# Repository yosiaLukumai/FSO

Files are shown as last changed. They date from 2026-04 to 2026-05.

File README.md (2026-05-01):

# FSO - Free Space Optics Communication System

A fully working wireless optical link built from off-the-shelf components for under $330. Custom circuits, fabricated hardware, desktop software, and an AI-driven adaptive power controller - designed, built, and field-tested by two Mechatronics students in Tanzania.

---

## The Problem

Laying fiber or cellular infrastructure in rural Tanzania is expensive and often logistically impossible. Yet connectivity demand is growing - for communities, drone applications, and satellite ground links. Commercial FSO systems exist but are priced far out of reach for most local use cases.

We wanted to answer one question: how far can careful engineering with minimal budget take you?

---

## What We Built

A complete FSO link - transmitter, receiver, alignment system, desktop software, and an adaptive power controller - all designed and fabricated from scratch.

| Layer | What |
|---|---|
| Optical | 650 nm off-shelf laser diode, custom fast-switching TX circuit |
| Receiver | Custom transimpedance amplifier (TIA), USB-to-serial interface |
| Alignment | CAD-designed frames, fabricated in-house from wood and PVC |
| Software | PyQt5 desktop app - file transfer, one-way chat, packet monitoring |
| Power control | Raspberry Pi + fog classifier + ATmega328P GPIO switching |

---

## Hardware

The transmitter drives a 650 nm laser diode through a custom fast-switching circuit designed for the modulation speeds needed for serial data. On the receiver end, a custom TIA converts the optical signal back to voltage, feeding a USB-to-serial converter that connects to the desktop application.

Maintaining line-of-sight is the hardest physical challenge in any FSO link. We designed alignment frames in CAD and fabricated them in-house.

<br>

| | |
|:---:|:---:|
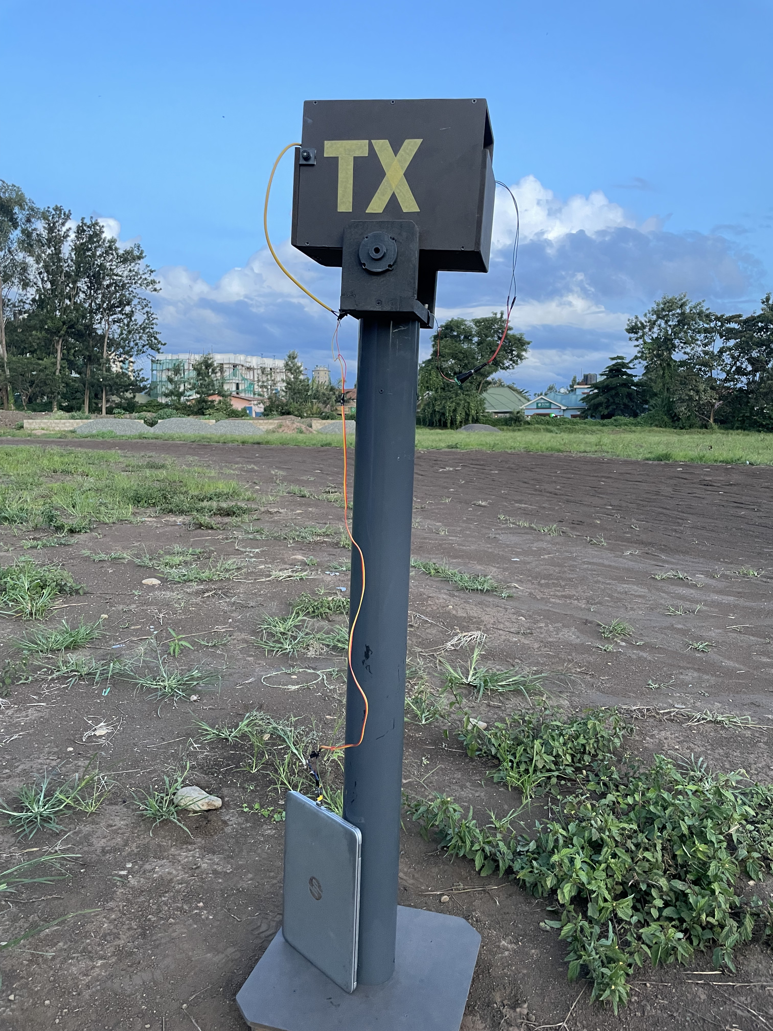
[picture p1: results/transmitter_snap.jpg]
TX unit in field
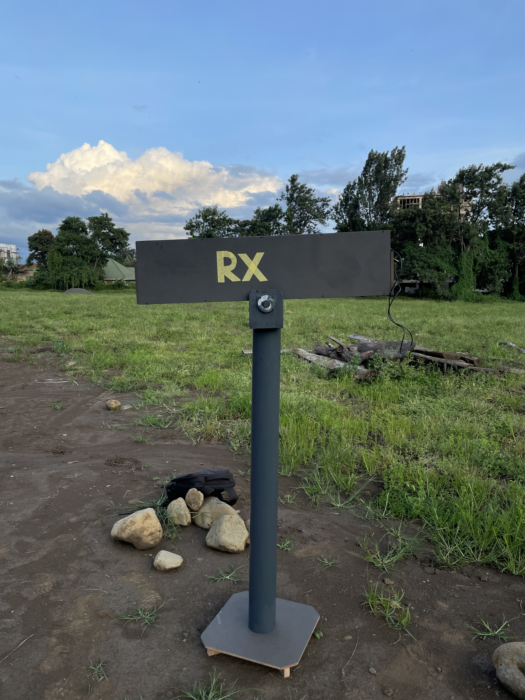
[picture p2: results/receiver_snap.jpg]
RX unit in field
|  |  |
| Transmitter (TX) | Receiver (RX) |

<table>
  <tr>
    <td align="center" width="50%">
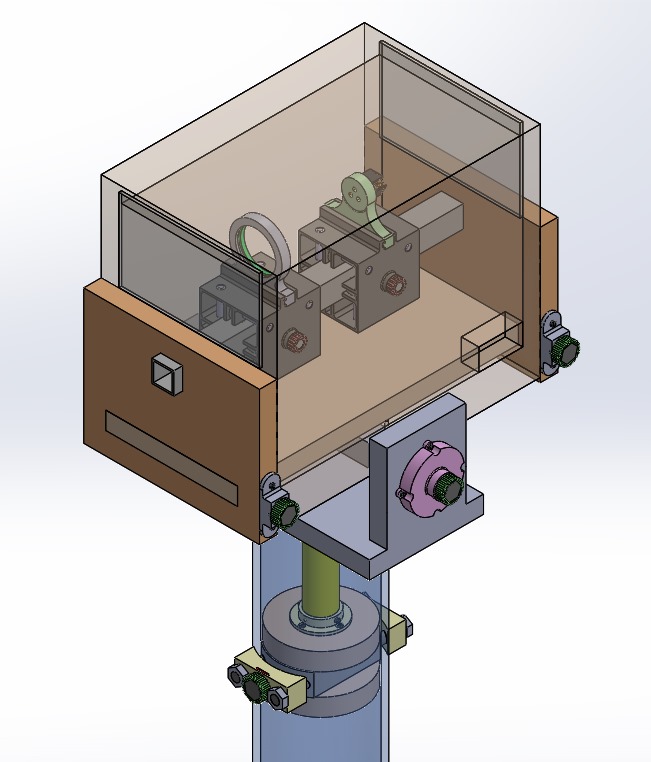
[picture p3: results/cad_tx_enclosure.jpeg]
      <br/>
      <em>CAD - TX enclosure</em>
    </td>
    <td align="center" rowspan="2" width="50%">
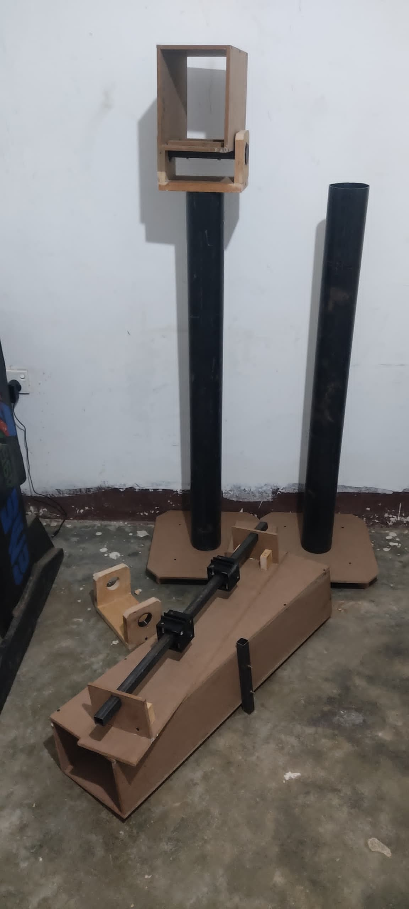
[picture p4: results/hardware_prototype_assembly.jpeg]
      <br/>
      <em>Fabricated prototypes</em>
    </td>
  </tr>
  <tr>
    <td align="center">
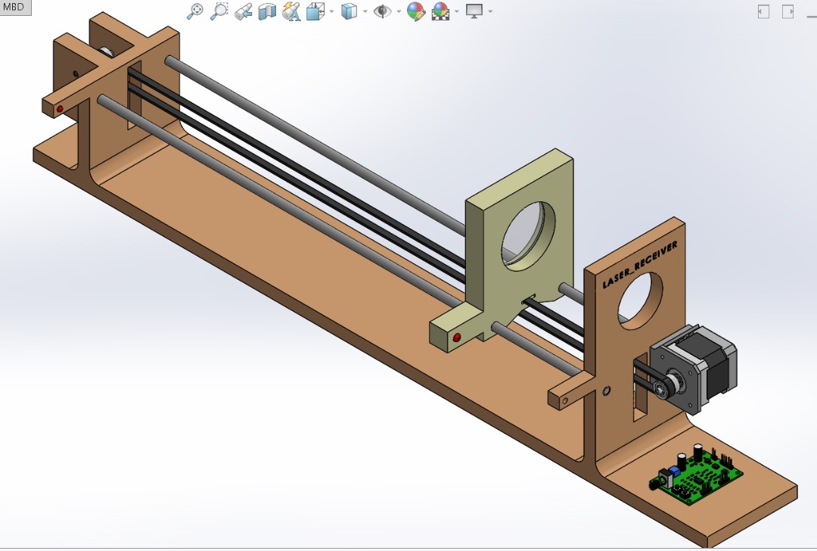
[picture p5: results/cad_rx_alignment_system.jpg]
      <br/>
      <em>CAD - RX alignment system</em>
    </td>
  </tr>
</table>

Schematics and bill of materials are in [`Hardware/`](Hardware/).

---

## Software

A desktop application on both ends of the link handles the full communication stack - serial connection management, file transfer (any file type), one-way text messaging, and live monitoring of transfer progress, speed, and missed packets.

<br>

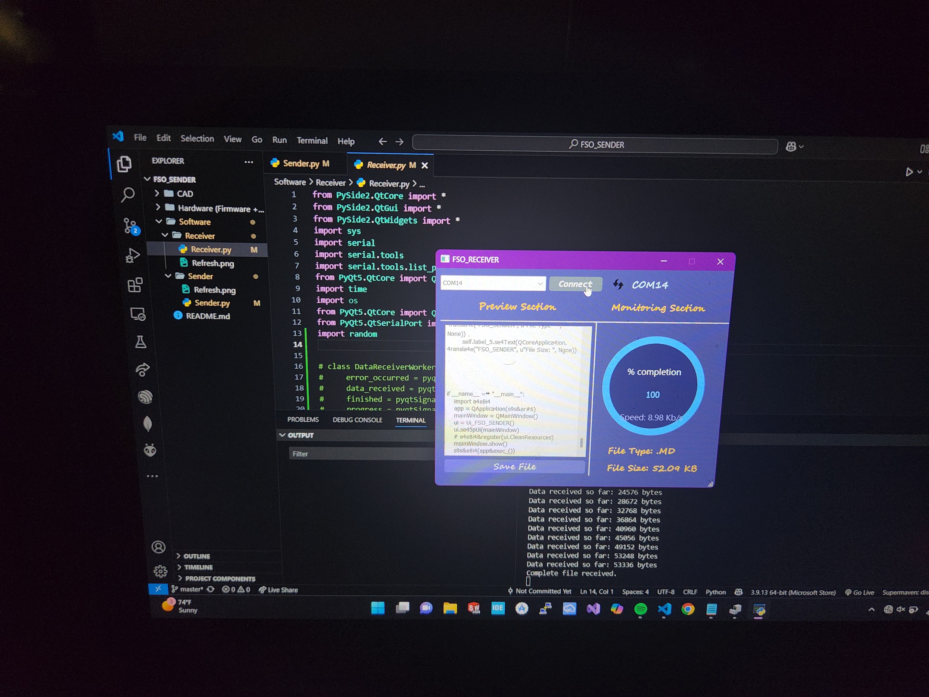
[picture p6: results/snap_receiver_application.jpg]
Receiver application

*Receiver app - 100% completion, file type and size confirmed.*

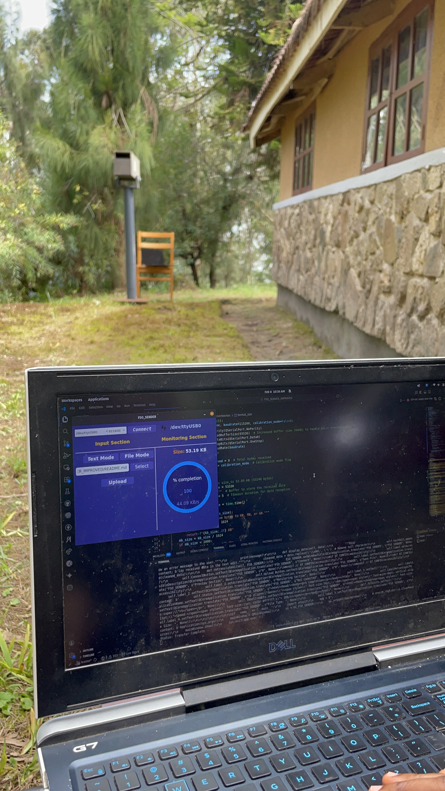
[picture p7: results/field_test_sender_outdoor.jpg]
Sender running outdoors

*Sender application running during outdoor field test.*

---

## Adaptive Power Control

Running the laser at full power continuously wastes energy - in clear conditions the link simply doesn't need it. We added a second layer: a Raspberry Pi runs a MobileNetV2 fog classifier (ONNX, edge-deployed) fused with live OpenWeatherMap visibility data. It outputs one of three states - CLEAR, MEDIUM_FOG, HEAVY_FOG - and an ATmega328P translates that into 2-bit GPIO control over the transmitter power.

The system only pushes full power when conditions actually demand it.

To test this under real fog, we traveled to Morogoro - the highland areas there gave us consistent fog cover we couldn't get at home.

<br>

Foggy Morogoro highlands
*Morogoro highlands - test environment for fog condition validation.*

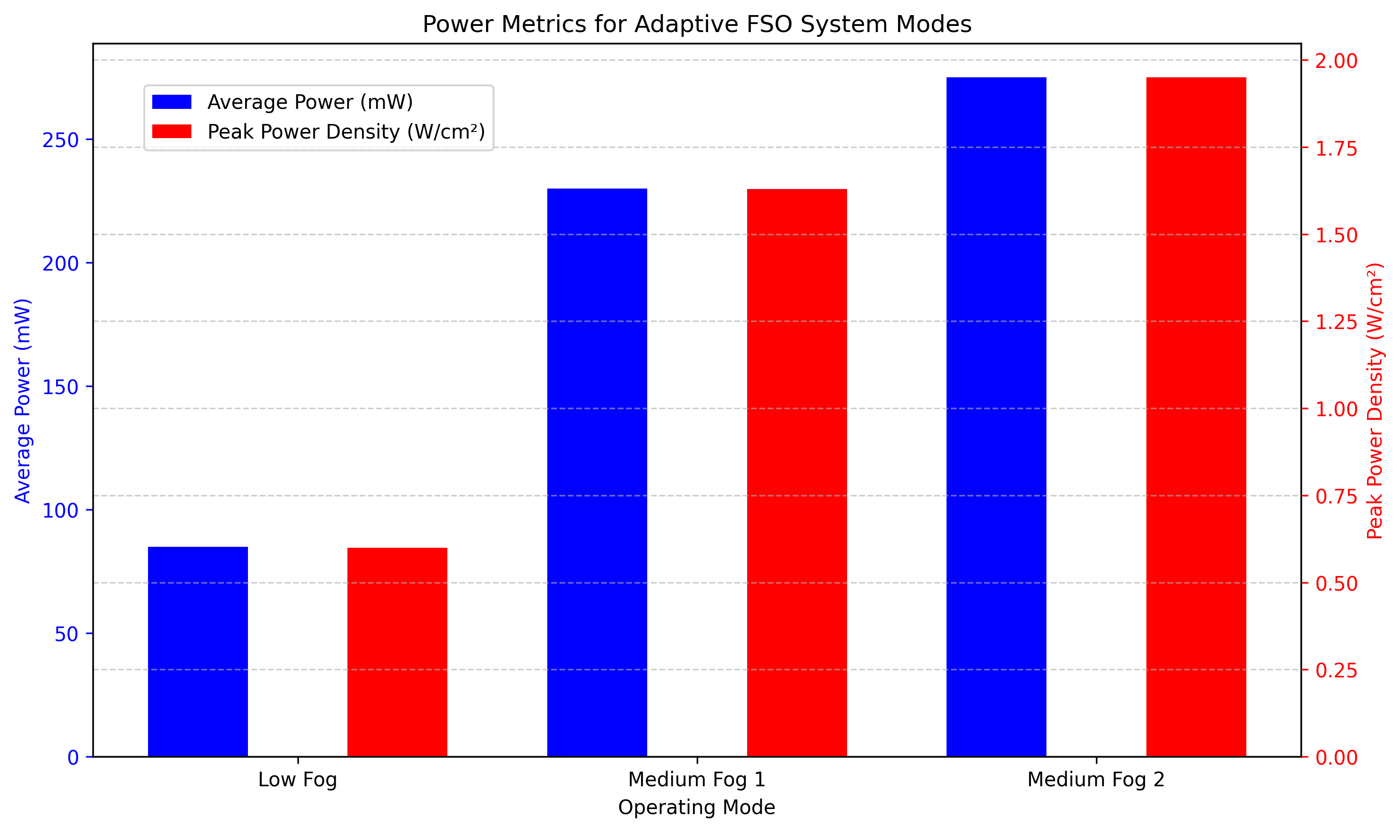
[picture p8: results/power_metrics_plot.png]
Power metrics

*Adaptive power output across fog conditions - power scales with visibility.*

The classifier code is in [`Classifier/`](Classifier/).

### Model Training

The fog classifier is MobileNetV2 fine-tuned in two phases on RESIDE-SOTS and DAWN fog datasets — first with a frozen backbone (head only), then fully fine-tuned. Trained on Kaggle using PyTorch, exported to ONNX for edge deployment on the Pi.

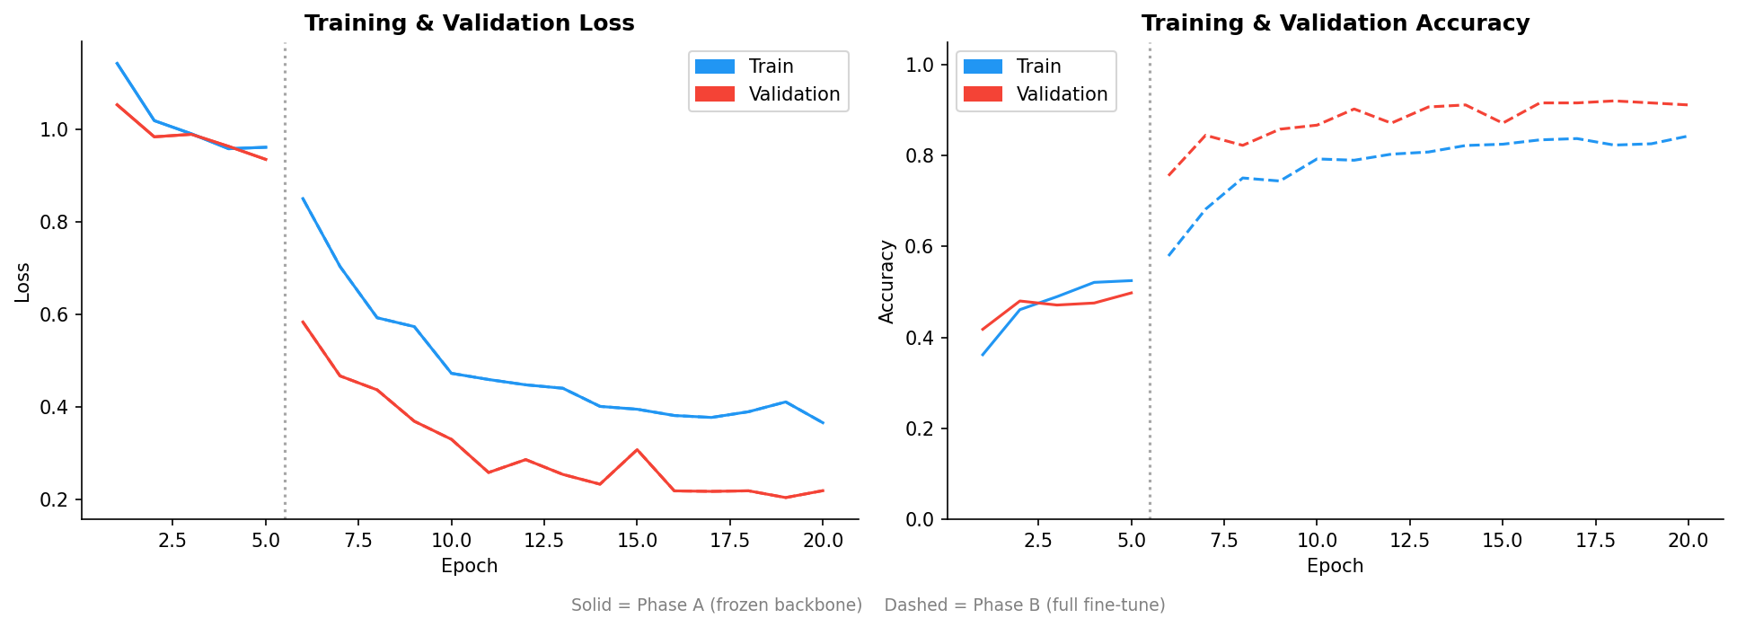
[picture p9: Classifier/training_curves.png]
Training curves

*Loss drops sharply after Phase B (full fine-tune) begins at epoch 5. Validation accuracy reaches ~91%.*

---

## Timeline

| Period | Milestone |
|---|---|
| Jul 2024 | Project started - research, component sourcing, circuit design |
| May – Aug 2025 | Hardware fabrication, alignment frames, first link established |
| Sep – Nov 2025 | Software development, open-field testing |
| Dec 2025 | Adaptive power system integrated |
| Jan – Feb 2026 | Morogoro fog testing, full system validation |

---

## Team

Two Mechatronics & Materials students, built outside class hours.

The goal was never to compete with commercial FSO systems. It was to understand what's actually possible with low cost and off-the-shelf parts - and to start building a path toward affordable optical links that could be deployed in rural Tanzania, on drones, or as part of satellite ground infrastructure.

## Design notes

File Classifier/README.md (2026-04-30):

# FSO Fog Classifier

Adaptive transmitter power control for Free Space Optics (FSO) links using
real-time fog classification fused with live weather data.

A Raspberry Pi camera captures the optical path, a MobileNetV2 ONNX model
classifies visibility, and 2-bit GPIO output selects the transmitter power level —
all in a closed loop.

---

## How It Works

```
  Pi Camera ──▶ Preprocess ──▶ ONNX FogClassifier (MobileNetV2)
                                        │
                                        ▼
  OpenWeatherMap API ──────▶ WeatherFusion (confidence-gated)
                                        │
                              ┌─────────▼──────────┐
                              │  GPIOPowerController│
                              │  CLEAR     → MIN    │
                              │  MED_FOG   → MED    │
                              │  HEAVY_FOG → MAX    │
                              └─────────────────────┘
```

**Fusion logic:**

| Model confidence | Decision |
|---|---|
| ≥ 0.85 | Model only |
| 0.60 – 0.84 | Weighted vote (model + API) |
| < 0.60 | API only |

---

## Hardware

| Component | Spec |
|---|---|
| Compute | Raspberry Pi 4 Model B (4 GB) |
| Camera | Pi Camera Module v2 or HQ Camera |
| OS | Raspberry Pi OS Lite 64-bit, kernel ≥ 6.1 |
| Python | 3.11+ |
| Power | 5 V / 3 A USB-C |

**GPIO wiring:**

| GPIO | Physical Pin | Role |
|---|---|---|
| GPIO17 | Pin 11 | Power bit 1 (MSB) |
| GPIO18 | Pin 12 | Power bit 0 (LSB) |
| GND | Pin 6 | Ground |

---

## Setup

### 1. Install dependencies

```bash
cd Classifier/
pip install -r requirements.txt

# Raspberry Pi only:
pip install picamera2 RPi.GPIO
```

### 2. Get the trained model

Training was done on Kaggle using PyTorch — view the full notebook here: [`fso_fog_classifier.ipynb`](fso_fog_classifier.ipynb).

The model is MobileNetV2 fine-tuned in two phases (frozen backbone → full fine-tune) on RESIDE-SOTS and DAWN fog datasets.

Training curves
*Training & validation loss/accuracy across 20 epochs — Phase A (frozen backbone) then Phase B (full fine-tune).*

To export the trained checkpoint to ONNX:

```bash
python export/export_onnx.py \
    --checkpoint checkpoints/mobilenetv2_fog_best.pt \
    --output     models/fog_classifier.onnx

# Verify numerical equivalence:
python export/verify_onnx.py \
    --checkpoint checkpoints/mobilenetv2_fog_best.pt \
    --onnx       models/fog_classifier.onnx
```

Expected: `PASS — max delta: X.XXe-06 (tolerance: 1.00e-05)`

### 3. Run the pipeline

```bash
# Production (Raspberry Pi)
python pipeline/main.py \
    --model_path models/fog_classifier.onnx \
    --api_key    YOUR_OWM_API_KEY \
    --lat        YOUR_LATITUDE \
    --lon        YOUR_LONGITUDE \
    --interval   15

# Mock mode — no hardware needed, good for testing the loop
python pipeline/main.py --mock --interval 5 --cycles 10
```

### 4. Run tests

```bash
pytest tests/ -v
```

All tests mock hardware (GPIO, camera, API) and run on any machine.

---

## Modules

| Path | Description |
|---|---|
| `fso_fog_classifier.ipynb` | Kaggle training notebook (MobileNetV2, two-phase fine-tuning) |
| `models/classifier.py` | PyTorch FogClassifier definition |
| `export/export_onnx.py` | Export checkpoint → ONNX |
| `export/verify_onnx.py` | Verify ONNX output matches PyTorch |
| `inference/predictor.py` | ONNX Runtime inference wrapper |
| `inference/camera.py` | picamera2 / OpenCV camera abstraction |
| `inference/weather_api.py` | OpenWeatherMap API client |
| `inference/gpio_controller.py` | 2-bit GPIO power controller |
| `pipeline/fusion.py` | Confidence-gated fusion layer |
| `pipeline/main.py` | Main orchestration loop |
| `tests/` | pytest unit tests |

---

## Performance Targets

| Metric | Target |
|---|---|
| Test accuracy | ≥ 90 % |
| Macro F1 | ≥ 0.88 |
| ONNX inference (Pi 4) | < 200 ms / frame |
| Pipeline cycle time | < 5 s (excl. sleep) |
| Memory (Pi 4) | < 512 MB RSS |

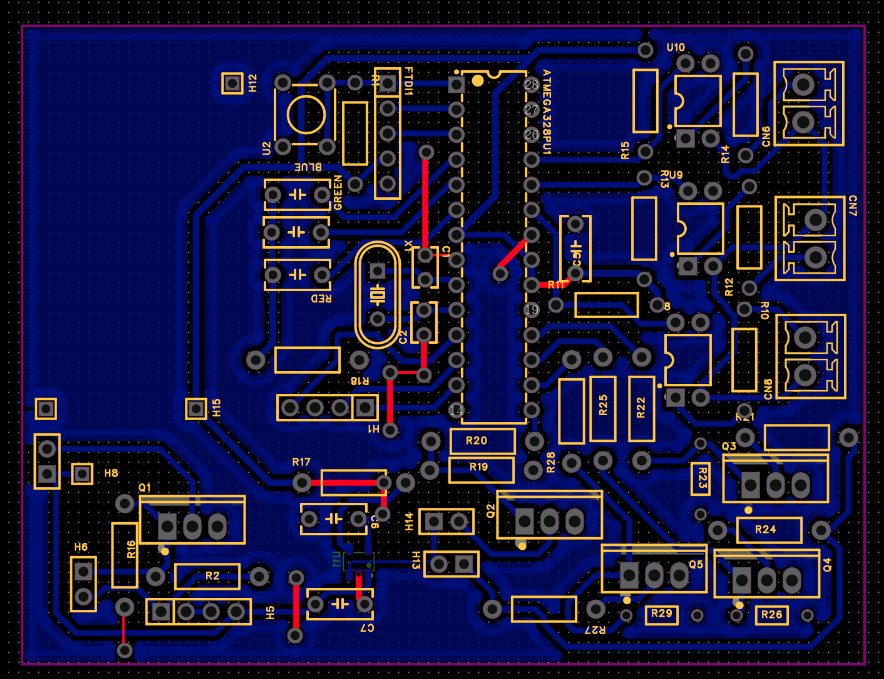
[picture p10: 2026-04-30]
Hardware/snaps circuit/Screenshot from 2026-04-30 11-48-44.png

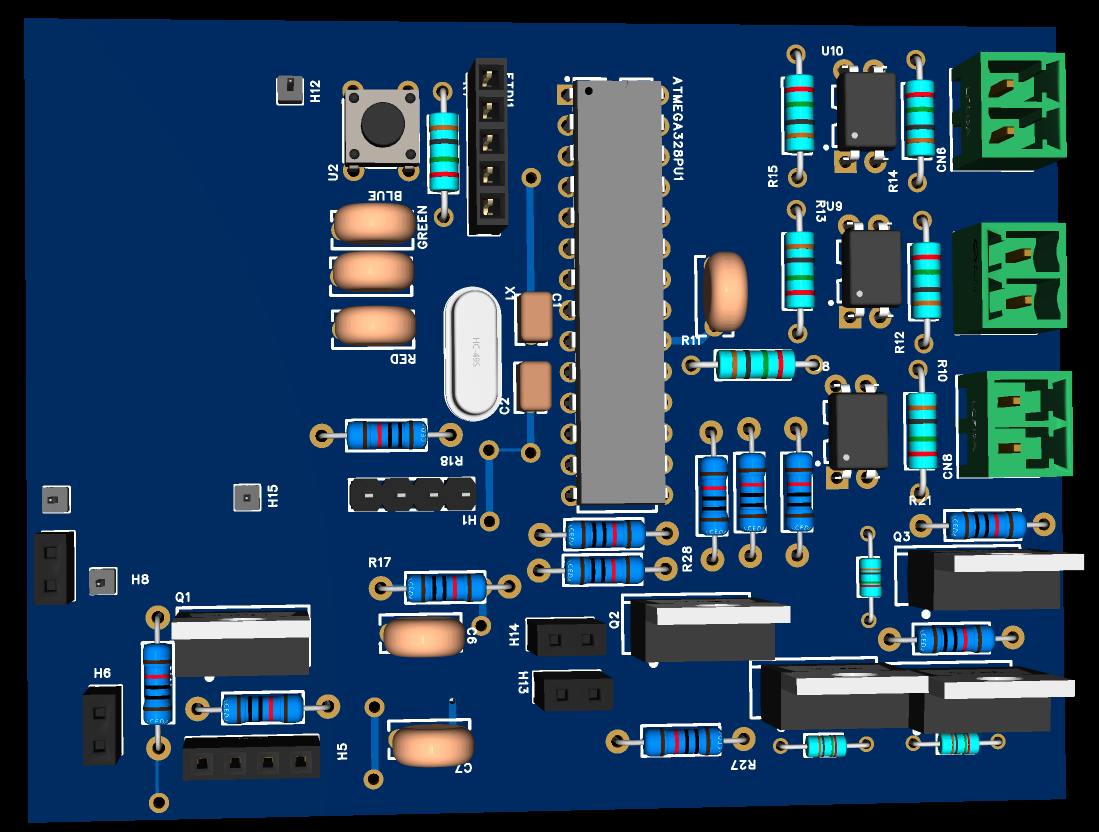
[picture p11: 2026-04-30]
Hardware/snaps circuit/Screenshot from 2026-04-30 11-48-31.png

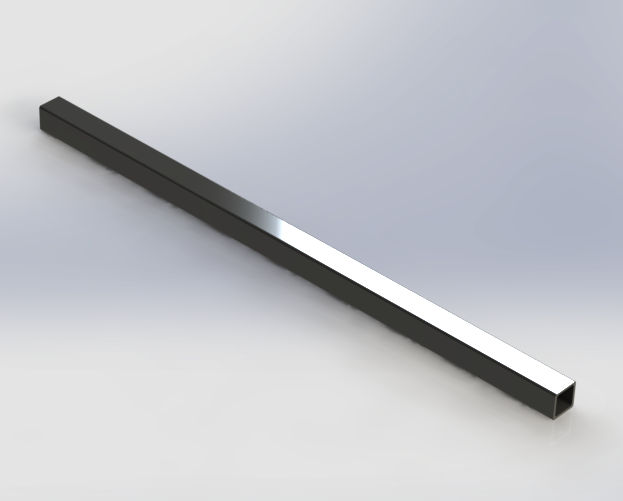
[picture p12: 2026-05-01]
CAD/square-pipes-1.snapshot.1/25x25x575Lx2.3t.png

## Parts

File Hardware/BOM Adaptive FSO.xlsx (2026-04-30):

No. | Quantity | Comment | Designator | Footprint | Value | Manufacturer Part | Manufacturer | Supplier Part | Supplier
1 | 1 | Raspberry PI 4B (with camera) |  |  |  | RASPBERRY PI 4B 2GB | Raspberry Pi | C53559230 | LCSC
2 | 2 | FT232RL (UART TO USB ) 12 MB/s full speed |  |  |  | FT232RL | FTDI CHIP
3 | 3 | Diodes |  |  | 1V@1A | D7G-T | DIODES | C7435972 | LCSC
4 | 2 | AD8015 Integrated Transimpedance Amplifier Board Module Single-Ended to Differential 240M Bandwidth 155Mbps Data Rate |  |  |  | AD8015
5 | 3 | KY-008 650nm Laser
6 | 3 | PD1450-35T52 Photodiode wavelength 680nm-1600nm Angle ±40°
7 | 1 | ATMEGA328-PU | ATMEGA328PU1 | DIP-28_L35.0-W6.5-P2.54-LS7.6-BL |  | ATMEGA328-PU | MICROCHIP | C613508 | LCSC
8 | 4 | 100nF | BLUE,C5,GREEN,RED | CAP-TH_L6.5-W3.0-P5.00-D0.6 | 100nF | DCS104M26Y5UH6FJ5A0 | SHM | C2896064 | LCSC
9 | 2 | 22pF | C1,C2 | CAP-TH_L4.0-W2.6-P2.50-D0.5 | 22pF | K220J15C0GF5TL2 | VISHAY | C2170230 | LCSC
10 | 2 | 10uF | C6,C7 | CAP-TH_L6.5-W3.0-P5.00-D0.6 | 10uF | DCS104M26Y5UH6FJ5A0 | SHM |  | LCSC
11 | 3 | WJ15EDGVC-3.81-2P | CN6,CN7,CN8 | CONN-TH_WJ15EDGVC-3.81-2P |  | WJ15EDGVC-3.81-2P | KANGNEX | C8396 | LCSC
12 | 1 | KH-2.54FH-1X5P-H8.5 | FTDI1 | HDR-TH_5P-P2.54-V-F |  | KH-2.54FH-1X5P-H8.5 | kinghelm | C2932671 | LCSC
13 | 1 | HDR-M_2.54_1x4P | H1 | HDR-TH_4P-P2.54-V-M
14 | 1 | 2.54-1*4P | H5 | HDR-TH_4P-P2.54-V-F |  | 2.54-1*4P | BOOMELE | C2718488 | LCSC
15 | 4 | 2.54-1*2P | H6,H11,H13,H14 | HDR-TH_2P-P2.54-V-F |  | 2.54-1*2P | BOOMELE | C49661 | LCSC
16 | 4 | HDR-M_2.54_1x1P | H8,H12,H15,H16 | HDR-TH_1P-V-M_XKB_X4611WV-01I-C28D40
17 | 5 | IRFZ44NPBF | Q1,Q2,Q3,Q4,Q5 | TO-220-3_L10.0-W4.5-P2.54-L |  | IRFZ44NPBF | Infineon | C2586 | LCSC
18 | 1 | 10kΩ | R1 | RES-TH_BD2.4-L6.3-P10.30-D0.6 | 10kΩ | RN1/4W10KFT/BA1 | Tyohm | C410695 | LCSC
19 | 11 | 1K | R2,R17,R18,R19,R20,R21,R22,R24,R25,R27,R28 | RES-TH_BD2.5-L6.5-P10.50-D0.6 | 1K | MFR0W4F1002A50 | UNI-ROYAL |  | LCSC
20 | 3 | 2.2k | R10,R12,R14 | RES-TH_BD2.4-L6.3-P10.30-D0.6 | 2.2k | RN1/4W10KFT/BA1 | Tyohm |  | LCSC
21 | 3 | 10k | R11,R13,R15 | RES-TH_BD2.4-L6.3-P10.30-D0.6 | 10k | RN1/4W10KFT/BA1 | Tyohm |  | LCSC
22 | 1 | 10kΩ | R16 | RES-TH_BD2.5-L6.5-P10.50-D0.6 | 10kΩ | MFR0W4F1002A50 | UNI-ROYAL | C57436 | LCSC
23 | 3 | 10kΩ | R23,R26,R29 | RES-TH_BD1.8-L3.2-P7.20-D0.4 | 10kΩ
24 | 1 | TC-6610 -6*6*9-260g | U2 | KEY-TH_4P-L6.0-W6.0-P4.50_TC-6610 |  | TC-6610 -6*6*9-260g | FG | C7528713 | LCSC
25 | 3 | PC817X2NSZW | U8,U9,U10 | DIP-4_L6.4-W4.6-P2.54-LS7.6-BL |  | PC817X2NSZW | SHARP | C5350 | LCSC
26 | 1 | SY6280AAC | U11 | SOT-23-5_L3.0-W1.7-P0.95-LS2.8-BR |  | SY6280AAC |  | C9900093550 | LCSC
27 | 1 | 16MHz | X1 | HC-49US_L11.5-W4.5-P4.88 | 16MHz | XIHCELNANF-16MHZ | TAITIEN | C295075 | LCSC

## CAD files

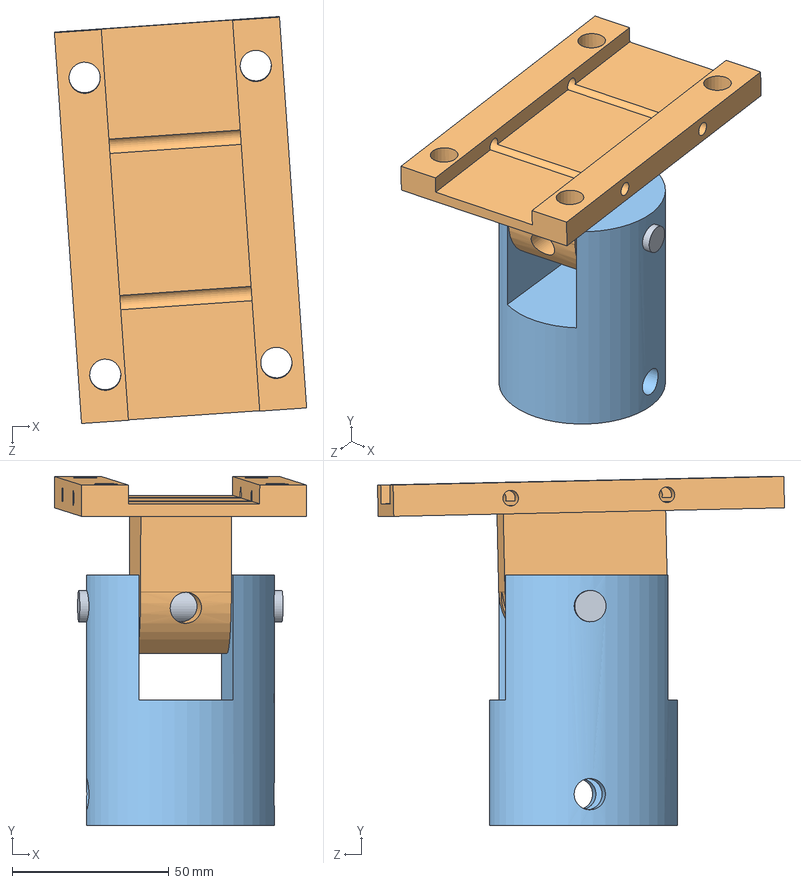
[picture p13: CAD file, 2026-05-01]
CAD/adjuster concept.SLDASM
80.5 x 111.4 x 129.9 mm
adster_concept
adster_concept_top
concept rod fll

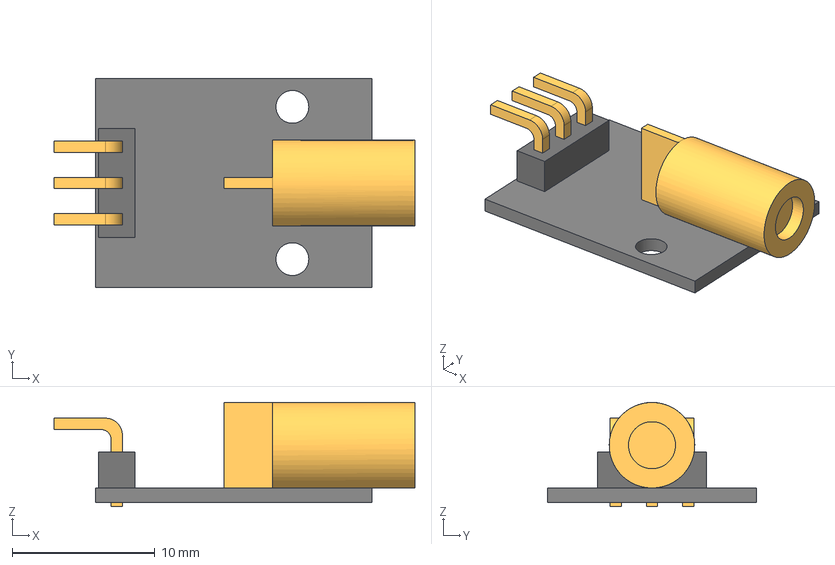
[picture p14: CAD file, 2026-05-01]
CAD/laser-module-5v-1.snapshot.1/LaserModule.stp
25.3 x 14.7 x 7.30 mm

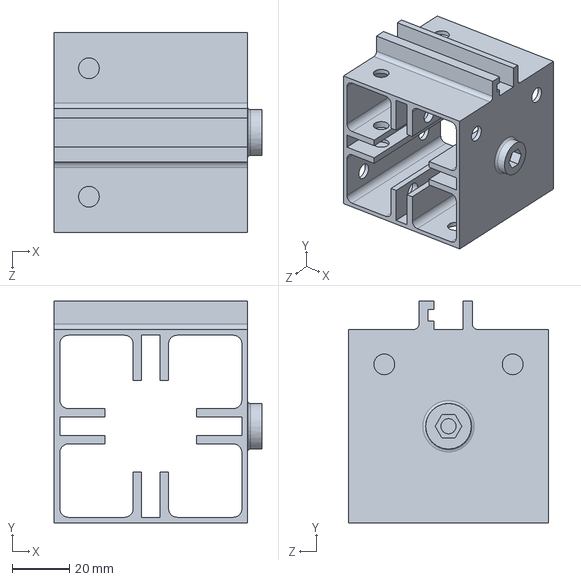
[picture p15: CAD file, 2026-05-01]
CAD/square-pipes-1.snapshot.1/lens_holder.SLDPRT
72.8 x 77.8 x 70.0 mm

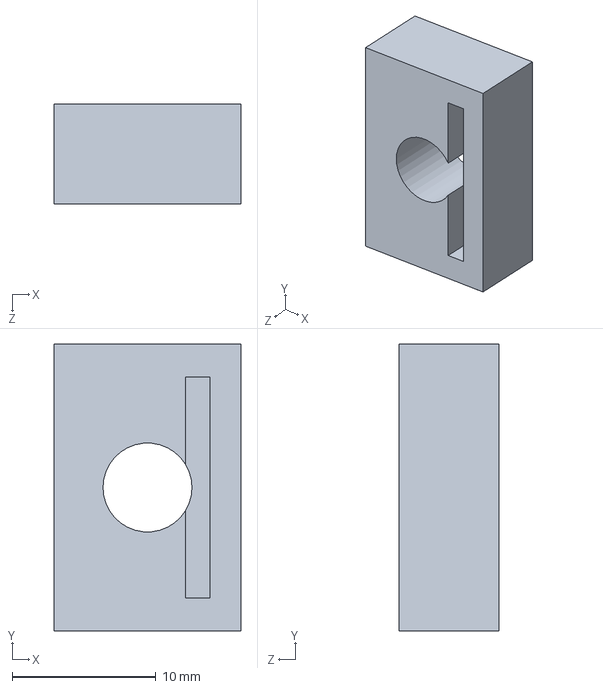
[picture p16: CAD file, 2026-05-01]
CAD/laser monting trial-0.1-offset.SLDPRT
13.0 x 20.0 x 7.00 mm

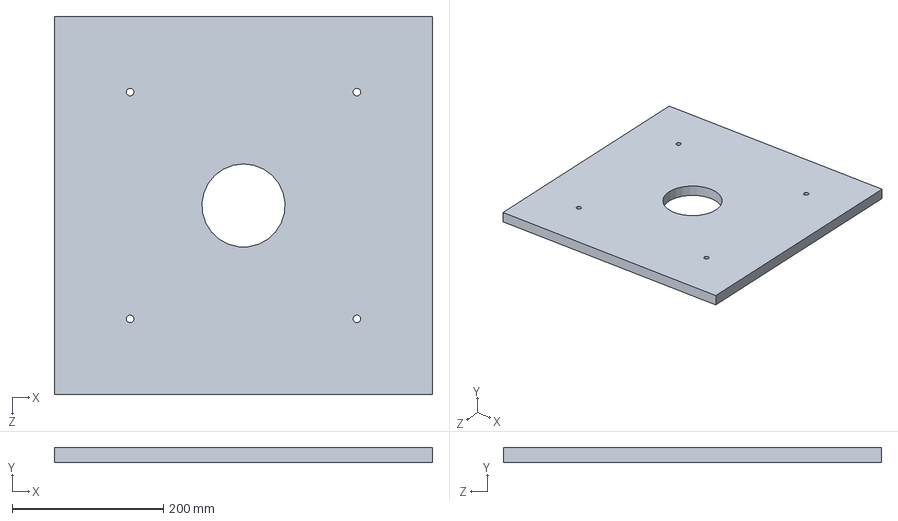
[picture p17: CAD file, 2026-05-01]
CAD/square-pipes-1.snapshot.1/base plate.SLDPRT
500.0 x 20.0 x 500.0 mm

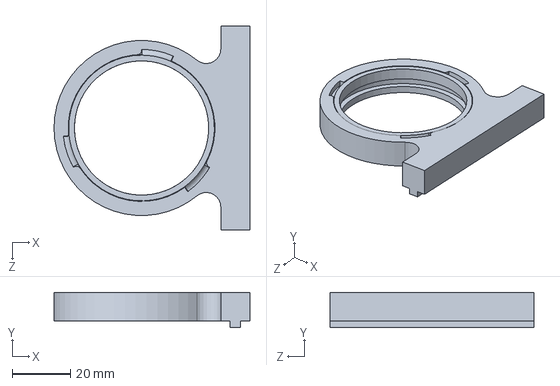
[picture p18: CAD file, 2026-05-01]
CAD/seal1.SLDPRT
67.2 x 12.1 x 70.0 mm

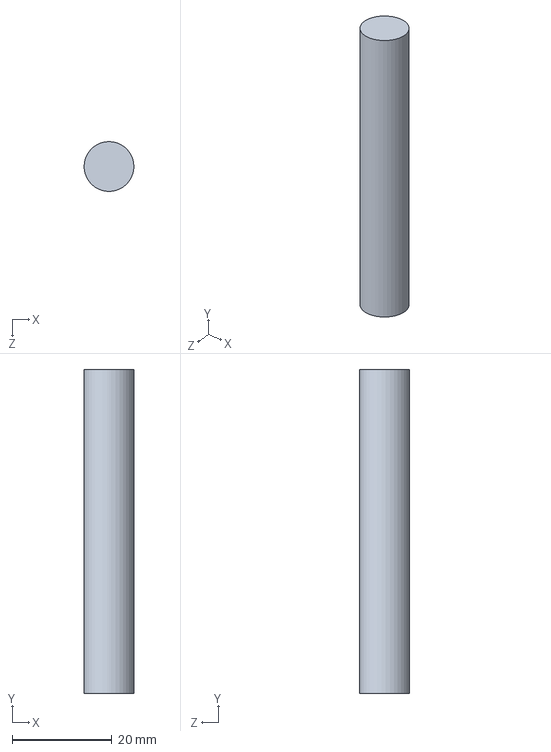
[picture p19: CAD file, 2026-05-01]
CAD/concept rod fll.SLDPRT
9.99 x 65.0 x 10.0 mm

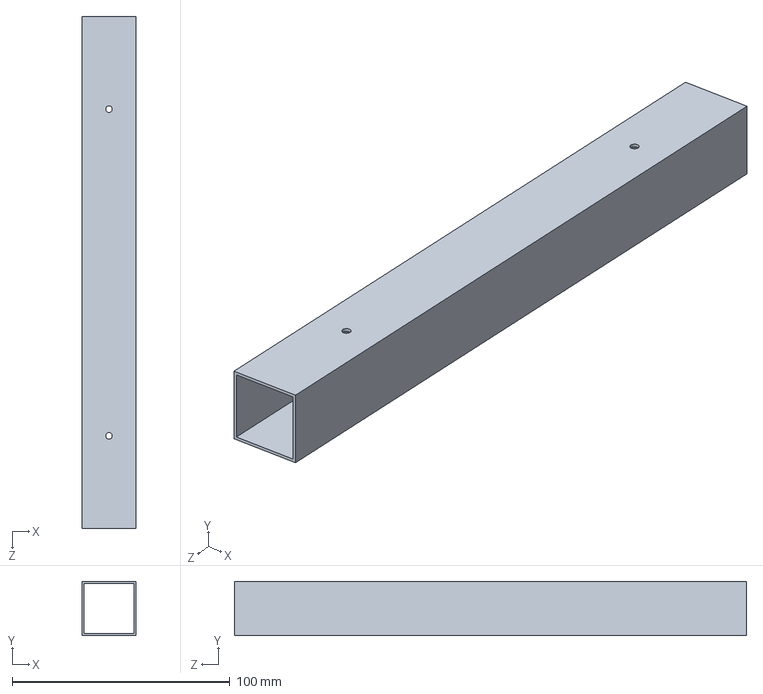
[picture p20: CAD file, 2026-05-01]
CAD/square-pipes-1.snapshot.1/small square pipe.SLDPRT
25.0 x 25.0 x 235.0 mm

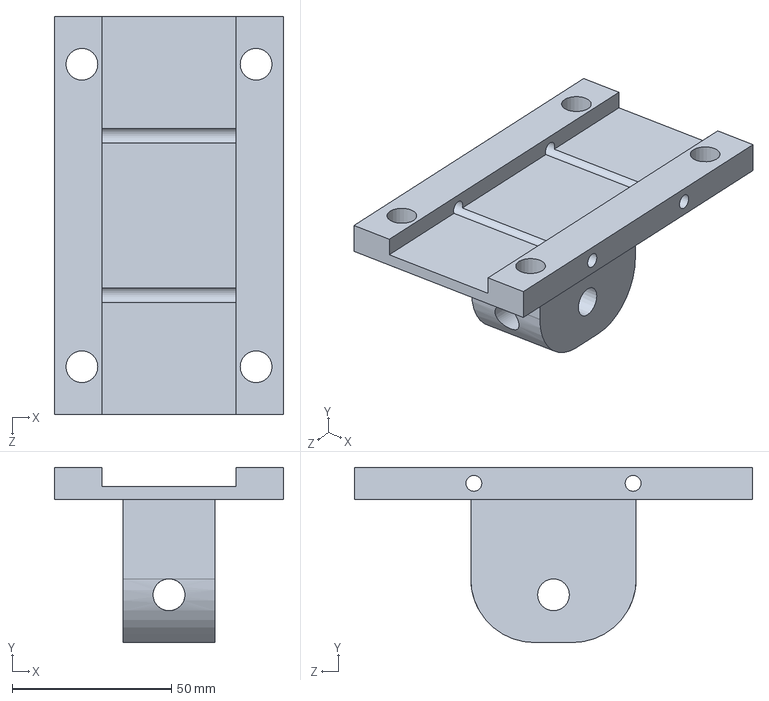
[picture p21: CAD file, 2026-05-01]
CAD/adster_concept_top.SLDPRT
72.0 x 55.0 x 125.0 mm

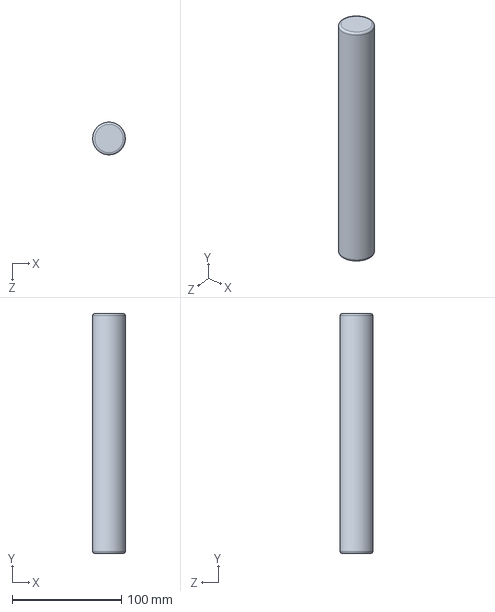
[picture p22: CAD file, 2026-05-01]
CAD/square-pipes-1.snapshot.1/wood(rotation joint).SLDPRT
30.0 x 220.0 x 30.0 mm

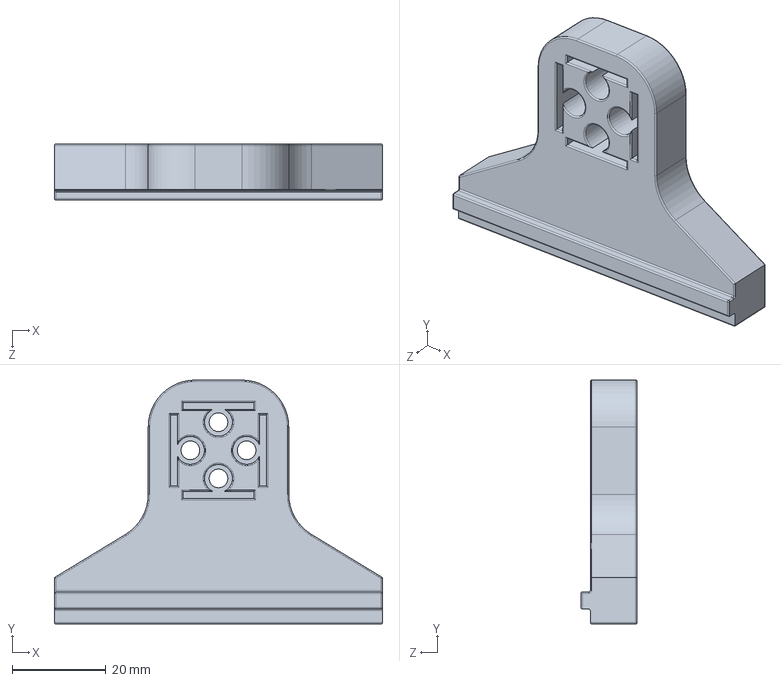
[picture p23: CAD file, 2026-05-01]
CAD/four lenses.SLDPRT
70.0 x 52.0 x 12.0 mm

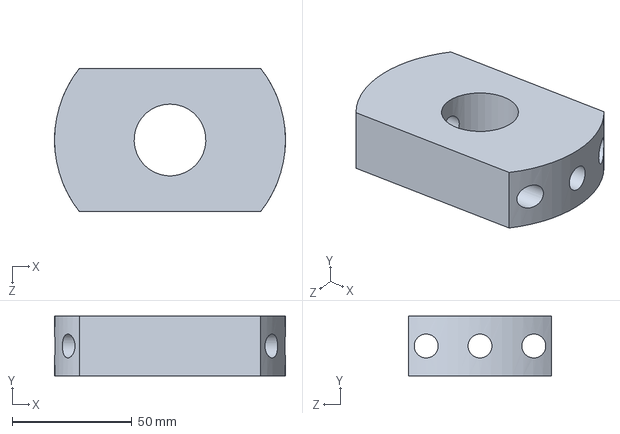
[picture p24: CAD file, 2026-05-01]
CAD/square-pipes-1.snapshot.1/rotational joint lock.SLDPRT
96.6 x 25.0 x 60.0 mm

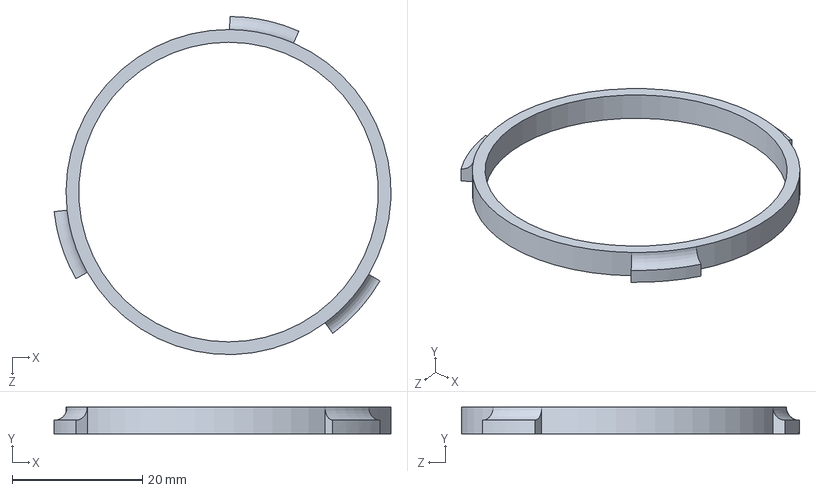
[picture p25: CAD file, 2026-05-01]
CAD/Move_face_tried_again.SLDPRT
51.7 x 4.10 x 51.9 mm

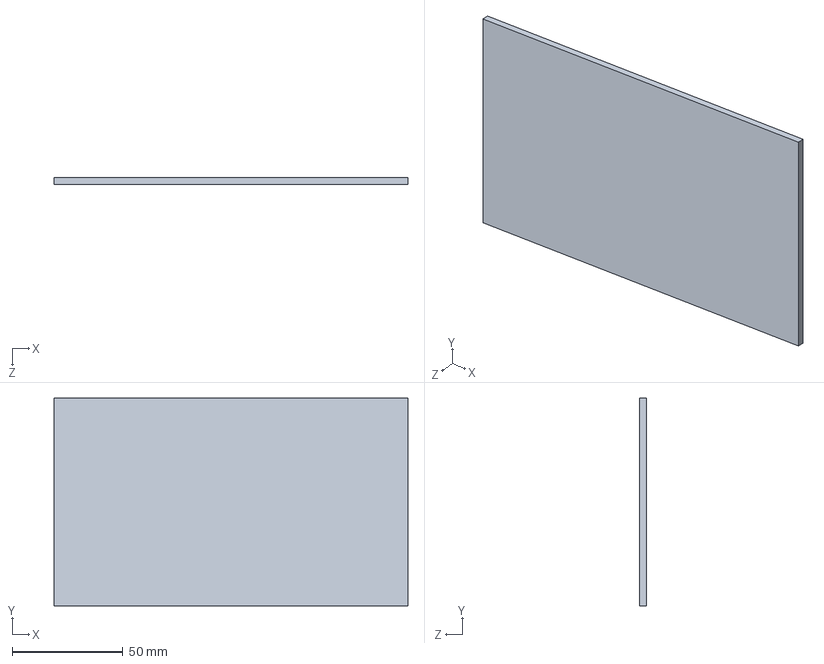
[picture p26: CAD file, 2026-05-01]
CAD/square-pipes-1.snapshot.1/glass.SLDPRT
160.0 x 94.0 x 3.00 mm

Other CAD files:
CAD/lasers and laser ho;der assembly.SLDASM
CAD/component holder and adjuster.SLDASM
CAD/square-pipes-1.snapshot.1/rotation-joint-link.SLDPRT
CAD/adster_concept.SLDPRT
CAD/LaserModule.SLDPRT
CAD/base.SLDPRT
CAD/bearing.SLDPRT
CAD/convex22_V2.0.SLDPRT
CAD/convex22_changed.SLDPRT
CAD/convexSeal1.SLDPRT
CAD/laser monting trial-0.2-offset.SLDPRT
CAD/laser monting trial.SLDPRT
CAD/laser-module-5v-1.snapshot.1/LaserModule.SLDASM
CAD/laser-module-housing.SLDPRT
CAD/m10 thread rods.SLDPRT
CAD/mod2.SLDPRT
CAD/pole.SLDPRT
CAD/rotational nut locker.SLDPRT
CAD/rotatonal joint external lock.SLDPRT
CAD/small screws.SLDPRT
CAD/square-pipes-1.snapshot.1/25mm square pipe.SLDPRT
CAD/square-pipes-1.snapshot.1/Door_Side_Locker_Inside.SLDPRT
CAD/square-pipes-1.snapshot.1/Door_Side_Locker_Outside.SLDPRT
CAD/square-pipes-1.snapshot.1/LensHolder_V2.STL
CAD/square-pipes-1.snapshot.1/Slot guider.SLDPRT
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

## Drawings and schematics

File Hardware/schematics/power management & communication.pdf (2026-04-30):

# GREEN BLUE

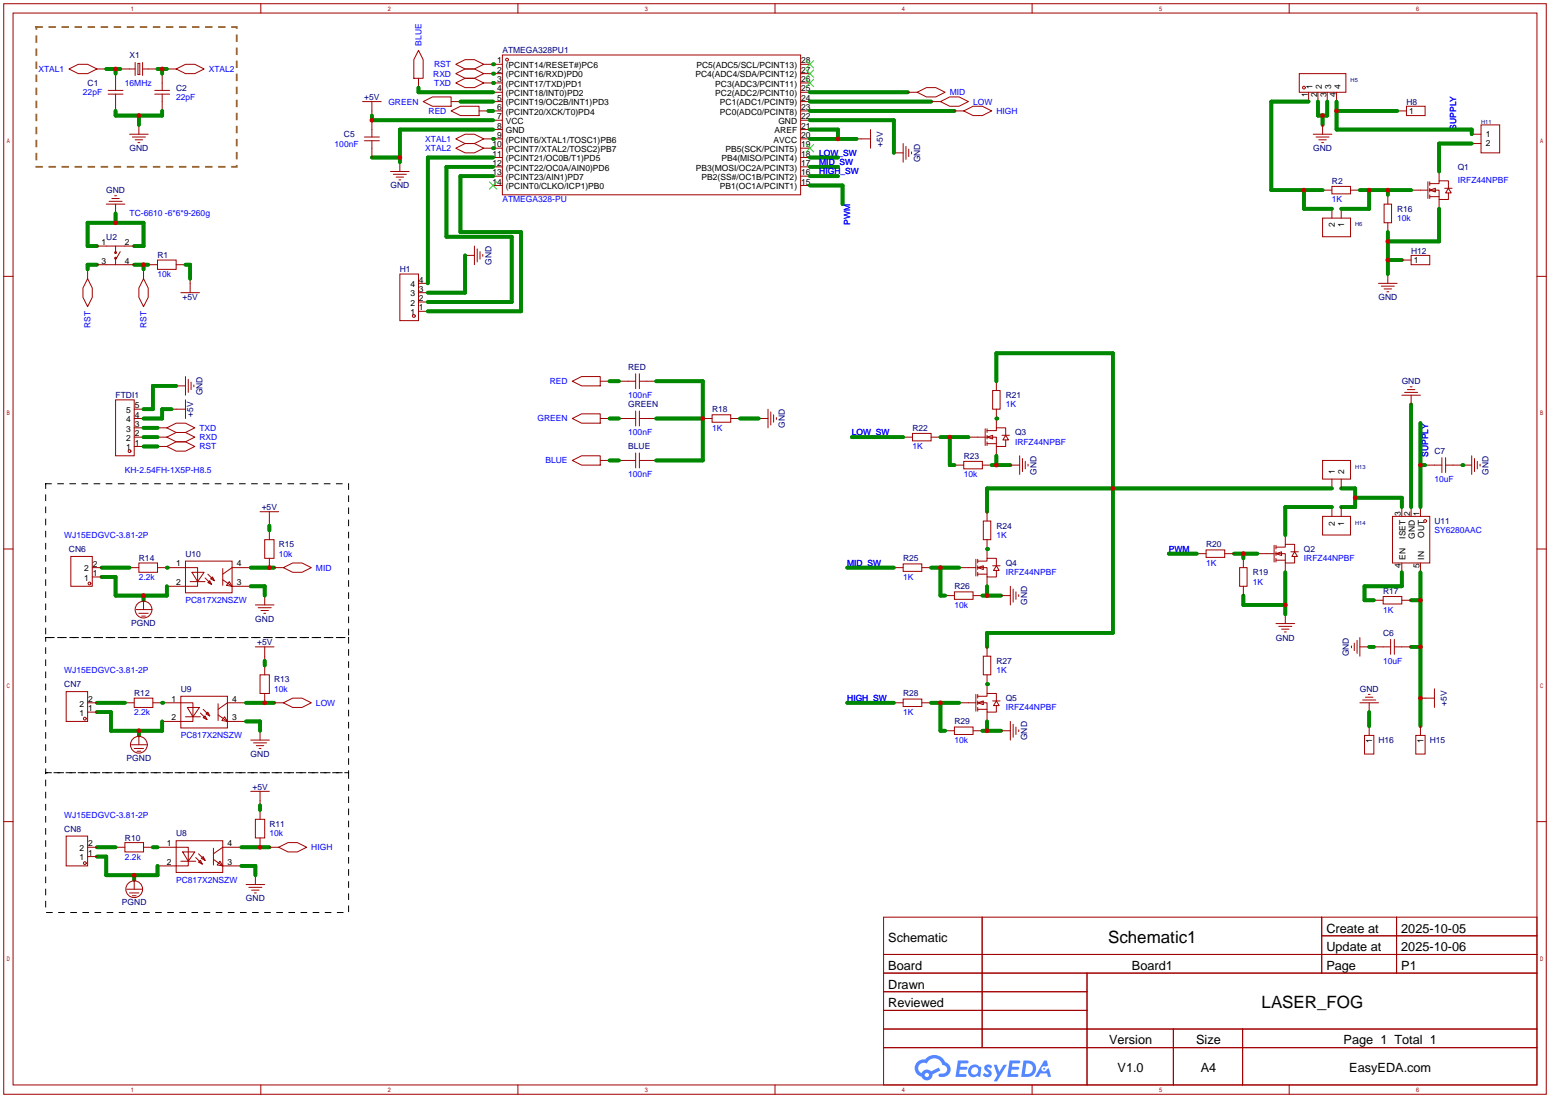
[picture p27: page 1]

Schematic | Schematic1 | Create at | 2025-10-05

Update at | 2025-10-06

Board | Board1 | Page | P1
Drawn | | LASER_FOG
Reviewed

Version | Size | Page 1 Total 1
V1.0 | A4 | EasyEDA.com

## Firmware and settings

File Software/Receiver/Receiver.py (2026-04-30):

from PySide2.QtCore import *
from PySide2.QtGui import *
from PySide2.QtWidgets import *
import sys
import serial
import serial.tools
import serial.tools.list_ports
from PyQt5.QtCore import QThread, pyqtSignal
import time
import os
from PyQt5.QtCore import QObject, pyqtSignal, QThread
from PyQt5.QtSerialPort import QSerialPort


class DataReceiverWorker(QObject):
    error_occurred = pyqtSignal(str)
    data_received = pyqtSignal(str) 
    finished = pyqtSignal() 
    progress = pyqtSignal(int)
    fileTypeSignal = pyqtSignal(str)
    fileSizeSignal = pyqtSignal(str)
    errorSignal = pyqtSignal(int)

    def __init__(self, port_name):
        super().__init__()
        self.serial_port = QSerialPort()
        self.serial_port.setPortName(port_name)
        self.serial_port.setFlowControl(QSerialPort.SoftwareControl)  # Using software control (XON/XOFF)
        self.serial_port.setParity(QSerialPort.NoParity)
        self.serial_port.setReadBufferSize(1024)  # Buffer size for reading data
        self.serial_port.setDataBits(QSerialPort.Data8)
        self.serial_port.setStopBits(QSerialPort.OneStop)
        self.serial_port.setBaudRate(115200)

        self.is_running = True

        self.expected_file_size = 0 
        self.expected_file_type = "" 
        self.received_data = b"" 
        self.header_buffer = ""
        self.in_header = False  
        self.timeout_duration = 5
        self.errorSize = 0
        self.last_received_time = time.time()


    def format_size(self, bytes_size):
        """
        Convert the size from bytes to KB, MB, or GB, depending on its magnitude.
        :param bytes_size: Size in bytes
        :return: Formatted string with the size in KB, MB, or GB
        """
        # Convert bytes to kilobytes
        kb_size = bytes_size / 1024

        if kb_size < 1000:
            # If size is less than 1000 KB, return in KB
            return f"{kb_size:.2f} KB"
        
        # Convert kilobytes to megabytes
        mb_size = kb_size / 1024

        if mb_size < 1000:
            # If size is less than 1000 MB, return in MB
            return f"{mb_size:.2f} MB"
        
        # Convert megabytes to gigabytes
        gb_size = mb_size / 1024

        # Return the size in GB
        return f"{gb_size:.2f} GB"


    def start_receiving(self):
        """Start the data reception process."""
        if not self.serial_port.open(QSerialPort.ReadOnly):
            self.error_occurred.emit(f"Failed to open port: {self.serial_port.errorString()}")
            return

        header_buf = ""
        header_parsed = False
        bytes_received = 0

        while self.is_running:
            if not self.serial_port.waitForReadyRead(100):
                # If we know the expected size and nothing is arriving, check timeout
                if header_parsed and self.expected_file_size > 0:
                    elapsed = time.time() - self.last_received_time
                    if elapsed > self.timeout_duration:
                        break
                continue

            data = self.serial_port.readAll().data()
            self.last_received_time = time.time()

            if not header_parsed:
                # Accumulate into header buffer until END_HEADER marker found
                try:
                    header_buf += data.decode('utf-8', errors='replace')
                except Exception:
                    header_buf += data.decode('latin-1', errors='replace')

                if "END_HEADER" in header_buf:
                    end_idx = header_buf.index("END_HEADER") + len("END_HEADER")
                    header_line = header_buf[:end_idx]
                    leftover    = header_buf[end_idx:].lstrip('\n')

                    # Parse: HEADER|FILE_TYPE:<t>|FILE_SIZE:<s>|CHUNK_SIZE:<c>|END_HEADER
                    try:
                        parts = {p.split(':')[0]: p.split(':')[1]
                                 for p in header_line.split('|')
                                 if ':' in p}
                        self.expected_file_type = parts.get('FILE_TYPE', 'unknown')
                        self.expected_file_size = int(parts.get('FILE_SIZE', 0))
                        self.fileTypeSignal.emit(self.expected_file_type)
                        self.fileSizeSignal.emit(self.format_size(self.expected_file_size))
                    except Exception as e:
                        self.error_occurred.emit(f"Header parse error: {e}")

                    header_parsed = True
                    self.received_data = leftover.encode('utf-8')
                    bytes_received = len(self.received_data)
            else:
                # Past the header — count raw bytes as they arrive
                self.received_data += data
                bytes_received = len(self.received_data)

                if self.expected_file_size > 0:
                    pct = min(int(bytes_received / self.expected_file_size * 100), 100)
                    self.progress.emit(pct)

                try:
                    self.data_received.emit(data.decode('utf-8', errors='replace'))
                except Exception:
                    pass

                # Done when we've received everything expected
                if bytes_received >= self.expected_file_size > 0:
                    break

        # ── Loss summary ────────────────────────────────────────────────────────
        if self.expected_file_size > 0:
            lost = max(self.expected_file_size - bytes_received, 0)
            self.errorSize = lost
            self.errorSignal.emit(lost)
            self.progress.emit(100)

        self.serial_port.close()
        self.finished.emit()

    def stop_receiving(self):
        """Stop the data reception and close the serial port."""
        self.is_running = False
        self.in_header = True
        if self.serial_port.isOpen():
            self.serial_port.close()
        print("Serial port closed successfully.")



class Ui_FSO_SENDER(object):
    def setupUi(self, FSO_SENDER):
        if not FSO_SENDER.objectName():
            FSO_SENDER.setObjectName(u"FSO_SENDER")
        FSO_SENDER.resize(620, 480)
        FSO_SENDER.setMinimumSize(QSize(620, 480))
        FSO_SENDER.setMaximumSize(QSize(620, 480))
        font = QFont()
        font.setFamily(u"Segoe Script")
        font.setPointSize(14)
        font.setBold(True)
        font.setWeight(75)
        FSO_SENDER.setFont(font)
        FSO_SENDER.setAutoFillBackground(False)
        FSO_SENDER.setStyleSheet(u"\n""QPushButton {\n""     background-color: #6262a2;\n""    color: white;\n""    border: none;\n""    padding: 1px 20px;\n""    font-size: 19px;\n""    border-radius: 5px;\n""}\n""\n""QPushButton:hover {\n""    background-color:  #6c757d ;\n""}\n""\n""QPushButton:pressed {\n""    background-color: #1c6399;\n""}\n""\n""QLabel {\n""    color: #333333;\n""    font-size: 19px;\n""}\n""\n""QLineEdit {\n""    border: 1px solid #dcdcdc;\n""    padding: 5px;\n""    border-radius: 5px;\n""}\n""\n""QLineEdit:focus {\n""    border: 1px solid #3498db;\n""}\n""\n""Line{\n""\n""}\n""\n""QMainWindow {\n""background-color:rgb(77, 77, 127);\n""}\n""\n""")
        self.centralwidget = QWidget(FSO_SENDER)
        self.centralwidget.setObjectName(u"centralwidget")
        self.horizontalLayoutWidget = QWidget(self.centralwidget)
        self.horizontalLayoutWidget.setObjectName(u"horizontalLayoutWidget")
        self.horizontalLayoutWidget.setGeometry(QRect(10, 10, 338, 41))
        self.horizontalLayout = QHBoxLayout(self.horizontalLayoutWidget)
        self.horizontalLayout.setObjectName(u"horizontalLayout")
        self.horizontalLayout.setContentsMargins(0, 0, 0, 0)
        self.ComportSelector = QComboBox(self.horizontalLayoutWidget)
        self.ComportSelector.setObjectName(u"ComportSelector")
        self.ComportSelector.setMinimumSize(QSize(220, 30))
        self.ComportSelector.setMaximumSize(QSize(16777215, 30))
        self.ComportSelector.setCursor(QCursor(Qt.PointingHandCursor))

        self.horizontalLayout.addWidget(self.ComportSelector)

        self.ConnectButton = QPushButton(self.horizontalLayoutWidget)
        self.ConnectButton.setObjectName(u"ConnectButton")
        self.ConnectButton.setMinimumSize(QSize(0, 30))
        self.ConnectButton.setMaximumSize(QSize(16777215, 30))
        font1 = QFont()
        font1.setFamily(u"Consolas")
        font1.setBold(True)
        font1.setItalic(True)
        font1.setWeight(75)
        self.ConnectButton.setFont(font1)
        self.ConnectButton.setCursor(QCursor(Qt.PointingHandCursor))
        self.ConnectButton.setStyleSheet(u";")

        self.horizontalLayout.addWidget(self.ConnectButton)

        self.verticalLayoutWidget_3 = QWidget(self.centralwidget)
        self.verticalLayoutWidget_3.setObjectName(u"verticalLayoutWidget_3")
        self.verticalLayoutWidget_3.setGeometry(QRect(90, 60, 166, 36))
        self.TtileBox = QVBoxLayout(self.verticalLayoutWidget_3)
        self.TtileBox.setObjectName(u"TtileBox")
        self.TtileBox.setContentsMargins(0, 0, 0, 0)
        self.label = QLabel(self.verticalLayoutWidget_3)
        self.label.setObjectName(u"label")
        font2 = QFont()
        font2.setFamily(u"Segoe Script")
        font2.setBold(True)
        font2.setWeight(75)
        self.label.setFont(font2)
        self.label.setLayoutDirection(Qt.LeftToRight)
        self.label.setStyleSheet(u"color: #fdc500; \n""background-color: none;\n""\n""")
        self.label.setAlignment(Qt.AlignLeading|Qt.AlignLeft|Qt.AlignVCenter)

        self.TtileBox.addWidget(self.label)

        self.Upload_Button = QPushButton(self.centralwidget)
        self.Upload_Button.setObjectName(u"Upload_Button")
        self.Upload_Button.setGeometry(QRect(20, 420, 311, 30))
        self.Upload_Button.setMinimumSize(QSize(0, 30))
        self.Upload_Button.setMaximumSize(QSize(16777215, 30))
        self.Upload_Button.setFont(font2)
        self.Upload_Button.setCursor(QCursor(Qt.PointingHandCursor))
        self.Upload_Button.setStyleSheet(u"")
        self.verticalLayoutWidget_4 = QWidget(self.centralwidget)
        self.verticalLayoutWidget_4.setObjectName(u"verticalLayoutWidget_4")
        self.verticalLayoutWidget_4.setGeometry(QRect(370, 60, 231, 36))
        self.TtileBox_2 = QVBoxLayout(self.verticalLayoutWidget_4)
        self.TtileBox_2.setObjectName(u"TtileBox_2")
        self.TtileBox_2.setContentsMargins(0, 0, 0, 0)
        self.label_2 = QLabel(self.verticalLayoutWidget_4)
        self.label_2.setObjectName(u"label_2")
        self.label_2.setFont(font2)
        self.label_2.setLayoutDirection(Qt.LeftToRight)
        self.label_2.setStyleSheet(u"color: #fdc500; \n""background-color: none;\n""\n""")
        self.label_2.setAlignment(Qt.AlignLeading|Qt.AlignLeft|Qt.AlignVCenter)

        self.TtileBox_2.addWidget(self.label_2)

        self.line = QFrame(self.centralwidget)
        self.line.setObjectName(u"line")
        self.line.setGeometry(QRect(10, 90, 621, 0))
        self.line.setMinimumSize(QSize(0, 0))
        self.line.setMaximumSize(QSize(16777215, 0))
        self.line.setStyleSheet(u"color: green;\n""")
        self.line.setFrameShape(QFrame.HLine)
        self.line.setFrameShadow(QFrame.Sunken)
        self.line_2 = QFrame(self.centralwidget)
        self.line_2.setObjectName(u"line_2")
        self.line_2.setGeometry(QRect(330, 110, 20, 401))
        self.line_2.setStyleSheet(u"")
        self.line_2.setFrameShape(QFrame.VLine)
        self.line_2.setFrameShadow(QFrame.Sunken)
        self.line_3 = QFrame(self.centralwidget)
        self.line_3.setObjectName(u"line_3")
        self.line_3.setGeometry(QRect(10, 100, 611, 21))
        self.line_3.setFrameShape(QFrame.HLine)
        self.line_3.setFrameShadow(QFrame.Sunken)
        self.verticalLayoutWidget_5 = QWidget(self.centralwidget)
        self.verticalLayoutWidget_5.setObjectName(u"verticalLayoutWidget_5")
        self.verticalLayoutWidget_5.setGeometry(QRect(410, 10, 160, 41))
        self.verticalLayout_3 = QVBoxLayout(self.verticalLayoutWidget_5)
        self.verticalLayout_3.setObjectName(u"verticalLayout_3")
        self.verticalLayout_3.setContentsMargins(0, 0, 0, 0)
        self.Status = QLabel(self.verticalLayoutWidget_5)
        self.Status.setObjectName(u"Status")
        self.Status.setFont(font2)
        self.Status.setStyleSheet(u"color:  #cae9ff; \n""background-color: none;")

        self.verticalLayout_3.addWidget(self.Status)

        self.label_3 = QLabel(self.centralwidget)
        self.label_3.setObjectName(u"label_3")
        self.label_3.setGeometry(QRect(370, 20, 21, 21))
        self.label_3.setCursor(QCursor(Qt.PointingHandCursor))
        self.label_3.setPixmap(QPixmap(u"Refresh.png"))
        self.label_3.setScaledContents(True)
        self.circularProgressBar_Main = QFrame(self.centralwidget)
        self.circularProgressBar_Main.setObjectName(u"circularProgressBar_Main")
        self.circularProgressBar_Main.setGeometry(QRect(350, 130, 240, 240))
        self.circularProgressBar_Main.setStyleSheet(u"background-color: none;")
        self.circularProgressBar_Main.setFrameShape(QFrame.NoFrame)
        self.circularProgressBar_Main.setFrameShadow(QFrame.Raised)
        self.circularProgressCPU = QFrame(self.circularProgressBar_Main)
        self.circularProgressCPU.setObjectName(u"circularProgressCPU")
        self.circularProgressCPU.setGeometry(QRect(10, 10, 220, 220))
        self.circularProgressCPU.setStyleSheet(u"QFrame{\n""	border-radius: 110px;	\n""	background-color: qconicalgradient(cx:0.5, cy:0.5, angle:90, stop:0.400 rgba(85, 170, 255, 255), stop:0.395 rgba(255, 255, 255, 0));\n""}")
        self.circularProgressCPU.setFrameShape(QFrame.StyledPanel)
        self.circularProgressCPU.setFrameShadow(QFrame.Raised)
        self.circularBg = QFrame(self.circularProgressBar_Main)
        self.circularBg.setObjectName(u"circularBg")
        self.circularBg.setGeometry(QRect(10, 10, 220, 220))
        self.circularBg.setStyleSheet(u"QFrame{\n""	border-radius: 110px;	\n""	background-color: rgba(85, 85, 127, 100);\n""}")
        self.circularBg.setFrameShape(QFrame.StyledPanel)
        self.circularBg.setFrameShadow(QFrame.Raised)
        self.circularContainer = QFrame(self.circularProgressBar_Main)
        self.circularContainer.setObjectName(u"circularContainer")
        self.circularContainer.setGeometry(QRect(25, 25, 190, 190))
        self.circularContainer.setBaseSize(QSize(0, 0))
        self.circularContainer.setStyleSheet(u"QFrame{\n""	border-radius: 95px;	\n""	background-color: rgb(58, 58, 102);\n""}")
        self.circularContainer.setFrameShape(QFrame.StyledPanel)
        self.circularContainer.setFrameShadow(QFrame.Raised)
        self.layoutWidget = QWidget(self.circularContainer)
        self.layoutWidget.setObjectName(u"layoutWidget")
        self.layoutWidget.setGeometry(QRect(10, 40, 171, 145))
        self.infoLayout = QGridLayout(self.layoutWidget)
        self.infoLayout.setObjectName(u"infoLayout")
        self.infoLayout.setContentsMargins(0, 0, 0, 0)
        self.labelAplicationName = QLabel(self.layoutWidget)
        self.labelAplicationName.setObjectName(u"labelAplicationName")
        font3 = QFont()
        font3.setFamily(u"Segoe UI")
        self.labelAplicationName.setFont(font3)
        self.labelAplicationName.setStyleSheet(u"color: #FFFFFF; background-color: none;")
        self.labelAplicationName.setAlignment(Qt.AlignCenter)

        self.infoLayout.addWidget(self.labelAplicationName, 0, 0, 1, 1)

        self.labelPercentageCPU = QLabel(self.layoutWidget)
        self.labelPercentageCPU.setObjectName(u"labelPercentageCPU")
        font4 = QFont()
        font4.setFamily(u"Roboto Thin")
        self.labelPercentageCPU.setFont(font4)
        self.labelPercentageCPU.setStyleSheet(u"color: rgb(115, 185, 255); padding: 0px; background-color: none;")
        self.labelPercentageCPU.setAlignment(Qt.AlignCenter)
        self.labelPercentageCPU.setIndent(-1)

        self.infoLayout.addWidget(self.labelPercentageCPU, 1, 0, 1, 1)

        self.labelCredits = QLabel(self.layoutWidget)
        self.labelCredits.setObjectName(u"labelCredits")
        self.labelCredits.setFont(font3)
        self.labelCredits.setStyleSheet(u"color: rgb(148, 148, 216); background-color: none;")
        self.labelCredits.setAlignment(Qt.AlignCenter)

        self.infoLayout.addWidget(self.labelCredits, 2, 0, 1, 1)

        self.circularBg.raise_()
        self.circularProgressCPU.raise_()
        self.circularContainer.raise_()
        self.FileInfo = QLabel(self.centralwidget)
        self.FileInfo.setObjectName(u"FileInfo")
        self.FileInfo.setGeometry(QRect(20, 360, 131, 31))
        font5 = QFont()
        font5.setFamily(u"SWItalt")
        font5.setBold(False)
        font5.setWeight(50)
        self.FileInfo.setFont(font5)
        self.FileInfo.setStyleSheet(u"color: #fb8500;\n""font-size:8 !important\n"";")
        self.textEdit = QTextEdit(self.centralwidget)
        self.textEdit.setObjectName(u"textEdit")
        self.textEdit.setGeometry(QRect(20, 120, 311, 291))
        self.textEdit.setStyleSheet(u"border-radius:12;")
        self.verticalLayoutWidget = QWidget(self.centralwidget)
        self.verticalLayoutWidget.setObjectName(u"verticalLayoutWidget")
        self.verticalLayoutWidget.setGeometry(QRect(380, 380, 221, 33))
        self.verticalLayout = QVBoxLayout(self.verticalLayoutWidget)
        self.verticalLayout.setObjectName(u"verticalLayout")
        self.verticalLayout.setContentsMargins(0, 0, 0, 0)
        self.label_4 = QLabel(self.verticalLayoutWidget)
        self.label_4.setObjectName(u"label_4")
        self.label_4.setFont(font2)
        self.label_4.setStyleSheet(u"color: #fdc500; ")
        self.label_4.setTextFormat(Qt.MarkdownText)

        self.verticalLayout.addWidget(self.label_4)

        self.verticalLayoutWidget_2 = QWidget(self.centralwidget)
        self.verticalLayoutWidget_2.setObjectName(u"verticalLayoutWidget_2")
        self.verticalLayoutWidget_2.setGeometry(QRect(380, 420, 221, 33))
        self.verticalLayout_2 = QVBoxLayout(self.verticalLayoutWidget_2)
        self.verticalLayout_2.setObjectName(u"verticalLayout_2")
        self.verticalLayout_2.setContentsMargins(0, 0, 0, 0)
        self.label_5 = QLabel(self.verticalLayoutWidget_2)
        self.label_5.setObjectName(u"label_5")
        self.label_5.setFont(font2)
        self.label_5.setStyleSheet(u"color: #fdc500; ")

        self.verticalLayout_2.addWidget(self.label_5)

        FSO_SENDER.setCentralWidget(self.centralwidget)
        self.statusbar = QStatusBar(FSO_SENDER)
        self.statusbar.setObjectName(u"statusbar")
        FSO_SENDER.setStatusBar(self.statusbar)
        self.pushButton_3 = QPushButton(self.centralwidget)
        self.pushButton_3.setObjectName(u"pushButton_3")
        self.pushButton_3.setGeometry(QRect(360, 10, 41, 41))
        self.pushButton_3.setCursor(QCursor(Qt.PointingHandCursor))
        self.pushButton_3.setStyleSheet(u"background-color:none;")
        icon = QIcon()
        icon.addFile(u"C:/Users/Yosia/Desktop/_/FSO/FSO_SENDER/Software/Receiver/Refresh.png", QSize(), QIcon.Normal, QIcon.Off)
        self.pushButton_3.setIcon(icon)
        self.pushButton_3.setIconSize(QSize(22, 22))
        FSO_SENDER.setCentralWidget(self.centralwidget)
        self.statusbar = QStatusBar(FSO_SENDER)
        self.statusbar.setObjectName(u"statusbar")
        FSO_SENDER.setStatusBar(self.statusbar)

        self.retranslateUi(FSO_SENDER)

        QMetaObject.connectSlotsByName(FSO_SENDER)


        self.pushButton_3.clicked.connect(self.ObtainSerialPort)
        self.ConnectButton.clicked.connect(self.ConnectPort)
        self.AvailableComports = []
        self.ComportConfigured = False
        self.workingComportName = ""
        self.ObtainSerialPort()
        self.worker = None
        self.thread = None
        QApplication.instance().aboutToQuit.connect(self.cleanup)
    
    # def cleanup(self):
    #     """Perform cleanup before application exits."""
    #     self.worker.stop_receiving()
    
    # def ConnectPort(self):
    #     if self.ComportSelector.currentText() != "":
    #          if not self.ComportConfigured:
    #             self.Status.setText(self.ComportSelector.currentText())
    #             self.workingComportName = self.ComportSelector.currentText()
    #             self.worker = DataReceiverWorker(self.workingComportName)
    #             self.ComportConfigured = True
    #             # self.thread = QThread()
    #             self.worker.start_receiving()
    #          else:
    #              self.stop_receiving()
    #     else:
    #         self.Status.setText("No comport")
       
    # def ObtainSerialPort(self):
    #     ports = serial.tools.list_ports.comports()
    #     self.ComportSelector.clear()
    #     if len(ports) <= 0:
    #         self.Status.setText("No comport")
    #     else:
    #         self.AvailableComports = ports
    #         self.Status.setText("Select Comport")
    #         for port in ports:
    #             self.ComportSelector.addItem(port.device)

    # def stop_receiving(self):
    #     """Stop the current data receiving process."""
    #     if self.worker:
    #         self.worker.serial_port.close()  # Close the current serial port
    #         self.worker.quit()  # Quit the thread
    #         self.worker.wait()  # Wait for the thread to finish
    #         self.worker = None
    #         self.thread = None

    # def show_error(self, message):
    #     """Show an error message to the user."""
    #     print(message)

    # def display_data(self, data):
    #     """Display received data in the text edit."""
    #     print(data)
    #     self.textEdit.append(data)
    def cleanup(self):
        """Perform cleanup before application exits."""
        self.stop_receiving()
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

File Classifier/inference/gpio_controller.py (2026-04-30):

from __future__ import annotations

import logging
from enum import Enum
from typing import Any, Optional

logger = logging.getLogger(__name__)


class PowerLevel(int, Enum):
    MIN    = 0  # CLEAR
    MEDIUM = 1  # MEDIUM_FOG
    MAX    = 2  # HEAVY_FOG


_CLASS_TO_POWER: dict[str, PowerLevel] = {
    "CLEAR":      PowerLevel.MIN,
    "MEDIUM_FOG": PowerLevel.MEDIUM,
    "HEAVY_FOG":  PowerLevel.MAX,
}


class GPIOPowerController:
    """2-bit GPIO power controller for FSO transmitter.

    PIN encoding:
        CLEAR      → GPIO17=0, GPIO18=0
        MEDIUM_FOG → GPIO17=0, GPIO18=1
        HEAVY_FOG  → GPIO17=1, GPIO18=0
    """

    GPIO17_PIN = 17
    GPIO18_PIN = 18

    PIN_STATES: dict[PowerLevel, tuple[int, int]] = {
        PowerLevel.MIN:    (0, 0),
        PowerLevel.MEDIUM: (0, 1),
        PowerLevel.MAX:    (1, 0),
    }

    def __init__(self, mock: bool = False) -> None:
        self._mock  = mock
        self._gpio: Optional[Any] = None
        self._current_level: Optional[PowerLevel] = None

        if not self._mock:
            self._init_gpio()

        if self._mock:
            logger.info("GPIOPowerController: MOCK mode (no hardware).")

    def _init_gpio(self) -> None:
        try:
            import RPi.GPIO as GPIO  # type: ignore[import]

            GPIO.setmode(GPIO.BCM)
            GPIO.setwarnings(False)
            GPIO.setup(self.GPIO17_PIN, GPIO.OUT, initial=GPIO.LOW)
            GPIO.setup(self.GPIO18_PIN, GPIO.OUT, initial=GPIO.LOW)
            self._gpio = GPIO
            logger.info("GPIO17 and GPIO18 configured as OUTPUT.")
        except ImportError:
            logger.warning("RPi.GPIO not found — switching to MOCK mode.")
            self._mock = True

    def _write_pins(self, pin17: int, pin18: int) -> None:
        if self._mock:
            logger.info("MOCK GPIO: GPIO17=%d GPIO18=%d", pin17, pin18)
            return
        gpio = self._gpio
        gpio.output(self.GPIO17_PIN, gpio.HIGH if pin17 else gpio.LOW)
        gpio.output(self.GPIO18_PIN, gpio.HIGH if pin18 else gpio.LOW)

    def set_power_level(self, level: PowerLevel) -> None:
        pin17, pin18 = self.PIN_STATES[level]
        logger.info("Power level: %s (GPIO17=%d, GPIO18=%d)", level.name, pin17, pin18)
        self._write_pins(pin17, pin18)
        self._current_level = level

    def set_from_visibility_class(self, visibility_class: str) -> None:
        cls_upper = visibility_class.upper()
        if cls_upper not in _CLASS_TO_POWER:
            raise ValueError(f"Unknown visibility class: '{visibility_class}'. Valid: {list(_CLASS_TO_POWER)}")
        self.set_power_level(_CLASS_TO_POWER[cls_upper])

    @property
    def current_level(self) -> Optional[PowerLevel]:
        return self._current_level

    def cleanup(self) -> None:
        if self._mock:
            return
        if self._gpio is not None:
            try:
                self._gpio.cleanup()
                logger.info("GPIO cleanup complete.")
            except Exception as exc:
                logger.warning("Error during GPIO cleanup: %s", exc)
            finally:
                self._gpio = None

    def __enter__(self) -> "GPIOPowerController":
        return self

    def __exit__(self, *args: Any) -> None:
        self.cleanup()

    def __repr__(self) -> str:
        return f"GPIOPowerController(mock={self._mock}, current_level={self._current_level})"

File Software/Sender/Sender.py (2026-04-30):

from PySide2.QtCore import *
from PySide2.QtGui import *
from PySide2.QtWidgets import *
from PyQt5.QtCore import QThread, pyqtSignal
import sys
import serial
import serial.tools
import serial.tools.list_ports
import os
import time



class DataSender(QThread):
    # Signal to update progress in the main thread
    progress = pyqtSignal(int)
    finished = pyqtSignal()
    error_occurred = pyqtSignal(str)
    file_size = pyqtSignal(str)
    speed_signal = pyqtSignal(float)

    def __init__(self, mode, com_port=None, file_path=None, text_data=None, baudrate=115200, chunk_size=1024):
        super().__init__()
        self.mode = mode  # 1 for file mode, 0 for text mode
        self.com_port = com_port
        self.file_path = file_path
        self.text_data = text_data
        self.baudrate = baudrate
        self.chunk_size = chunk_size
        self.serial_port = None  # This will hold the serial connection

    def create_header(self, file_type, file_size, chunk_size):
        """
        Create a header string that contains file information.
        Format: "HEADER|FILE_TYPE:<file_type>|FILE_SIZE:<file_size>|CHUNK_SIZE:<chunk_size>|END_HEADER\n"
        """
        header = f"HEADER|FILE_TYPE:{file_type}|FILE_SIZE:{file_size}|CHUNK_SIZE:{chunk_size}|END_HEADER\n"
        return header.encode('utf-8')  # Return encoded header

    def set_com_port(self):
        """ Set up the serial port connection. """
        if self.com_port is None:
            self.error_occurred.emit("No COM port provided.")
            return False

        try:
            # Set the serial port (replace baudrate with your preferred rate)
            self.serial_port = serial.Serial(self.com_port, baudrate=self.baudrate, timeout=1)
            return True
        except Exception as e:
            self.error_occurred.emit(f"Error connecting to {self.com_port}: {str(e)}")
            return False

    def format_size(self, bytes_size):
        """
        Convert the size from bytes to KB, MB, or GB, depending on its magnitude.
        :param bytes_size: Size in bytes
        :return: Formatted string with the size in KB, MB, or GB
        """
        # Convert bytes to kilobytes
        kb_size = bytes_size / 1024

        if kb_size < 1000:
            # If size is less than 1000 KB, return in KB
            return f"{kb_size:.2f} KB"
        
        # Convert kilobytes to megabytes
        mb_size = kb_size / 1024

        if mb_size < 1000:
            # If size is less than 1000 MB, return in MB
            return f"{mb_size:.2f} MB"
        
        # Convert megabytes to gigabytes
        gb_size = mb_size / 1024

        # Return the size in GB
        return f"{gb_size:.2f} GB"

    def get_file_size(self):
        """ Return the size of the file or text data. """
        return os.path.getsize(self.file_path) if self.mode == 1 else len(self.text_data.encode('utf-8'))

    def run(self):
        """ Main function run in the thread. """
        if not self.set_com_port():
            return  # Exit if COM port couldn't be set up

        try:
            # Create header based on the mode (file or text)
            file_type = "mp4" if self.mode == 1 else "text"
            file_size = self.get_file_size()
            header = self.create_header(file_type, file_size, self.chunk_size)

            # Send the header first
            self.serial_port.write(header)
            # time.sleep(2)
            print(f"Header sent: {header.decode('utf-8')}")

            if self.mode == 1:
                self.send_file()
            else:
                self.send_text()
        except Exception as e:
            print(e)
            self.error_occurred.emit(f"Error: {str(e)}")
        finally:
            # Ensure the serial port is closed when done
            if self.serial_port is not None:
                self.serial_port.close()
            self.finished.emit()

    def send_file(self):
        """Send file data in chunks after sending the header."""
        if self.file_path is None:
            self.error_occurred.emit("No file selected.")
            return

        # Get file size
        file_size = os.path.getsize(self.file_path)
        print(f"Size: {self.format_size(file_size)}")
        self.file_size.emit(str(self.format_size(file_size)))
        total_chunks = file_size // self.chunk_size + (1 if file_size % self.chunk_size != 0 else 0)
        print(f"Sending file of size {file_size} bytes in {total_chunks} chunks.")
        start_time = time.time()
        bytes_sent = 0

        with open(self.file_path, 'rb') as file:
            for chunk_index in range(total_chunks):
                content = file.read(self.chunk_size)
                # print(f"Sending chunk: {content[:50]}...")  # Print the first 50 bytes of the chunk
                self.serial_port.write(content)
                bytes_sent += len(content)  # Track total bytes sent

                # Calculate elapsed time
                elapsed_time = time.time() - start_time
                if elapsed_time > 0:  # Avoid division by zero
                    speed = bytes_sent / elapsed_time  # Bytes per second
                    self.speed_signal.emit(speed)  # Emit speed
                self.progress.emit(int((chunk_index + 1) / total_chunks * 100))

    def send_text(self):
        """Send text data in chunks after sending the header."""
        if self.text_data is None:
            self.error_occurred.emit("No text data provided.")
            return

        # Start time for speed calculation
        start_time = time.time()
        bytes_sent = 0  # Initialize total bytes sent

        # Encode text
        text_data = self.text_data.encode('utf-8')  # Encode the text
        text_size = len(text_data)  # Get size in bytes
        self.file_size.emit(str(self.format_size(text_size)))  # Emit the file size
        total_chunks = text_size // self.chunk_size + (1 if text_size % self.chunk_size != 0 else 0)
        print(f"Sending text of size {text_size} bytes in {total_chunks} chunks.")

        for chunk_index in range(total_chunks):
            # Slice the text data into chunks
            chunk = text_data[chunk_index * self.chunk_size:(chunk_index + 1) * self.chunk_size]
            print(f"Sending chunk: {chunk[:50]}...")  # Print the first 50 bytes of the chunk
            self.serial_port.write(chunk)  # Send the chunk
            bytes_sent += len(chunk)  # Track total bytes sent
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

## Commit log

2026-04-30 Full-stack free space optics links, Classifier model + Hardware (schematics + BOM) and software
    [BOM Adaptive FSO.xlsx]
2026-05-01 adding CAD files all parts
    [25mm square pipe.SLDPRT, Door_Side_Locker_Inside.SLDPRT, Door_Side_Locker_Outside.SLDPRT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]
